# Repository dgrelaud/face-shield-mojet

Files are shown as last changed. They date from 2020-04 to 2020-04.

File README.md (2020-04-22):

Mojet V2 - face shield
======================

Visière de protection, rapide à imprimer & monter

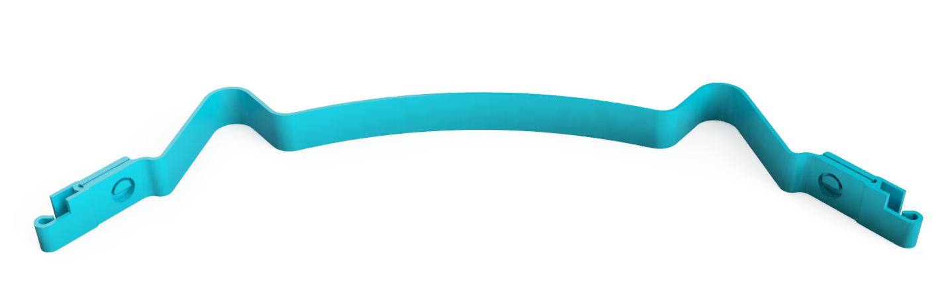
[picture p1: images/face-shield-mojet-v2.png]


Source Fusion 360 : https://a360.co/2yt3Tsa

# Caractéristiques du support de visière 

- 🍕 **Simple à imprimer** : 0 % de remplissage
- 🚀 Rapide à assembler : **seulement 2 trous de perforeuse standard** dans la feuille A4 transparente
- 🍟 Extrêmement compact : **15 pièces par impression** sur plateau 22 x 20 cm **sans empiler**
- 💎 **Très robuste** grâce à un système de pince et de crochet
- ⚡️ Rapide à démonter / monter pour nettoyage
- 👍 Une seule pièce (pas de clip)
- 💆 Face plastique avant (front) très souple pour améliorer le confort

# Évolution à venir : 

- Boucle pour élastique intégrée
- Kit pour remplacer les élastiques par des bandes de feuilles transparentes

# Matériel requis

- le support de visière mojet
- une feuille A4 transparente 100 à 400 um (testé avec 200um)
- une perforeuse dont l'écart du trou par rapport au bord de la feuille est de 11mm et le diamètre du trou est de 5,5mm
- une élastique
- deux boucles comme celles de New shield visière solidaire (possibilité de les intégrer)

# Instruction d'impression

- Plastique  PLA 
- Hauteur de couche : 0.3 mm
- 0% de remplissage
- 2 périmètres

# Historique des versions

- 2020-04-20 - V2 (actuelle)
- 2020-04-16 - V1 : perçage de la feuille compliqué, dépendant de la largeur de l'élastique

# Comparaison avec d'autres visières

Avec ces paramètres sur PrusaSlicer : Buse 0.4, 0% de remplissage, 2 périmètres, 50mm / s, PLA, 0.3 mm par couche

| Critère | Yann Vodable v25b | Yann Vodable v22 | Newshield-shark-v1-1 | Visor | Prusa shield RC3  | Mojet V2 |
|---|---|---|---|---|---|---|
| Quantité par plateau | 8 | 8 | 7 | 2 | 4 | 15 |
| Consommation plastique | 5,49g | 10,28g | 10,95g | 12g | 46g | 6,51g |
| Temps d'impression | 24min | 35min | 42min | 40min | 134min | 24min |
| Facilité du 1er assemblage | C | C | A | B | C | B |
| Rapidité démontage / montage | B | B | A | A | A | A |
| Simplicité usage / nettoyage | B | B | B | A | B | B |
| Solidité fixation | A | A | B | B | B | A |
| Rigidité visière 200um | ? | ? | A | ? | ? | B |
| Simplicité d'impression 3D | A | A | C | A | ? | ? |
| Ecartement visière / tête | A | A | A | B | A | A |

# Images

Vidéo démo démontage / montage :

Watch the video (https://youtu.be/Tu5RRXyYcv0)

Exemples d'impression 

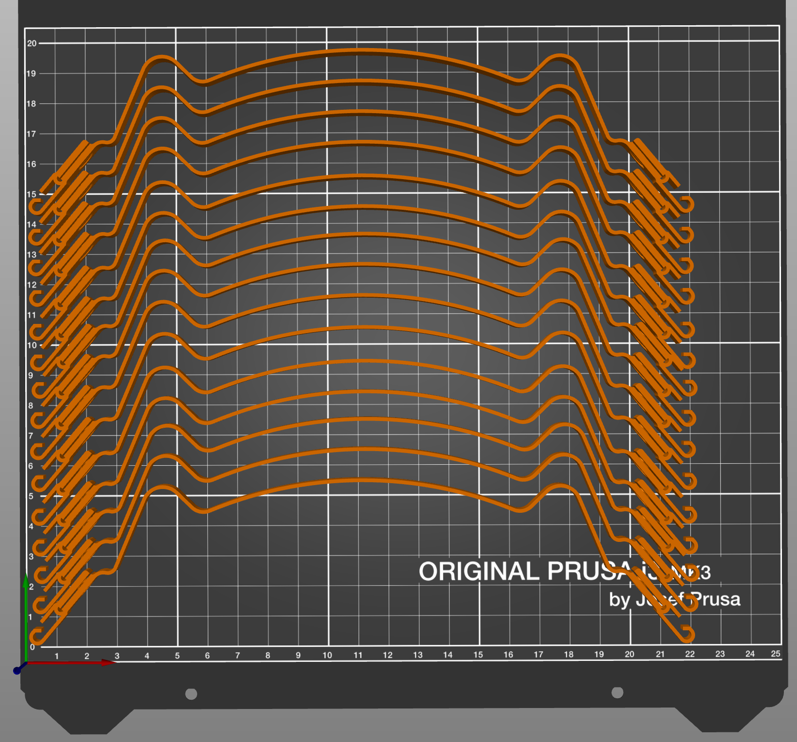
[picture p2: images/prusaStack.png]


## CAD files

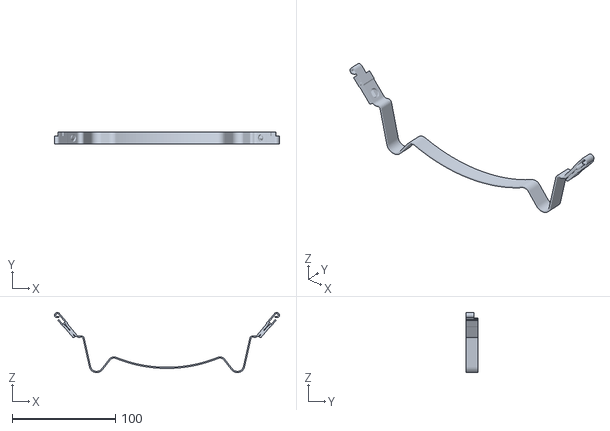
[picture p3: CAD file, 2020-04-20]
face-shield-mojet-v2.stl
217.5 x 12.0 x 58.2
